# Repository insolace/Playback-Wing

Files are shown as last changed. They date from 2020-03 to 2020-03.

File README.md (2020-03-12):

# Playback-Wing
Concept by Survivor Sound (http://www.survivorsound.com/)

Proof of concept prototype developed by Eric Bateman in 2018

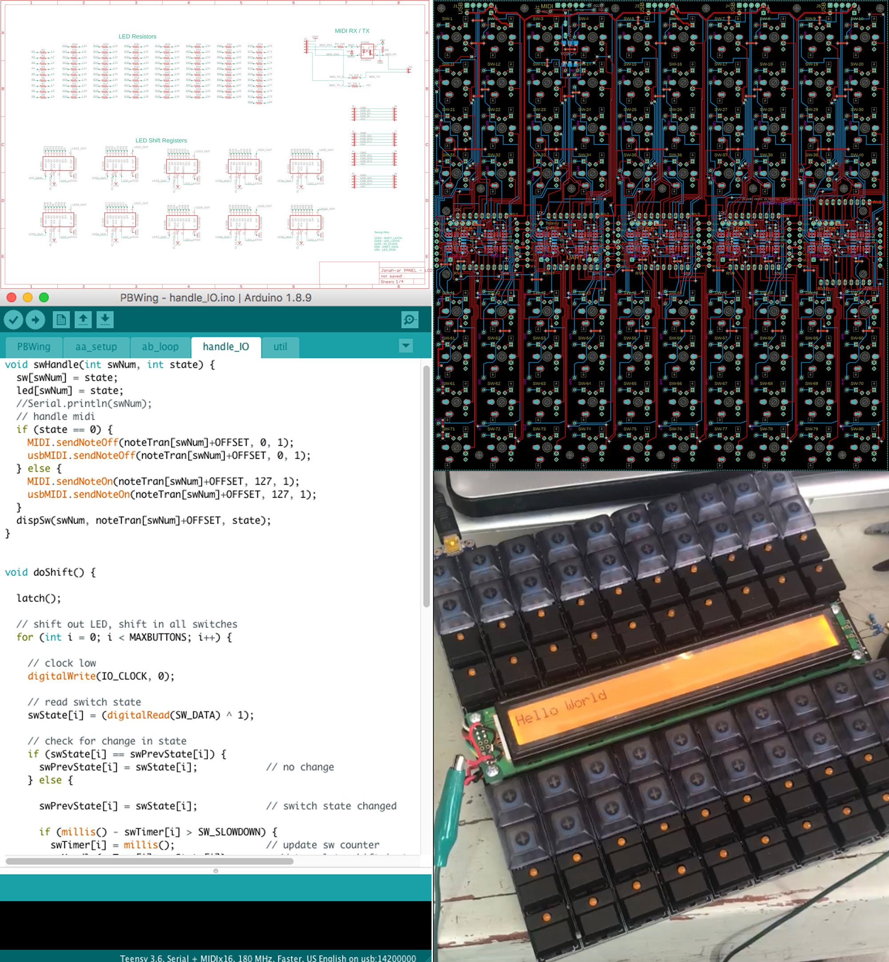
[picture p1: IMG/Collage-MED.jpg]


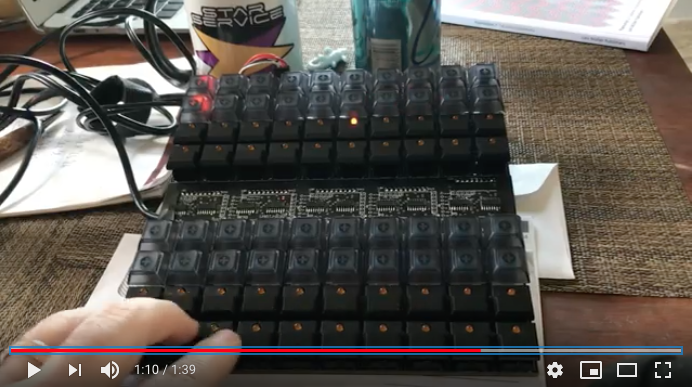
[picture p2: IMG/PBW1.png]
MIDI Demo Video (https://www.youtube.com/watch?v=q78MsimvOyE)
<br>
MIDI DEMO VIDEO (with cat at the end)

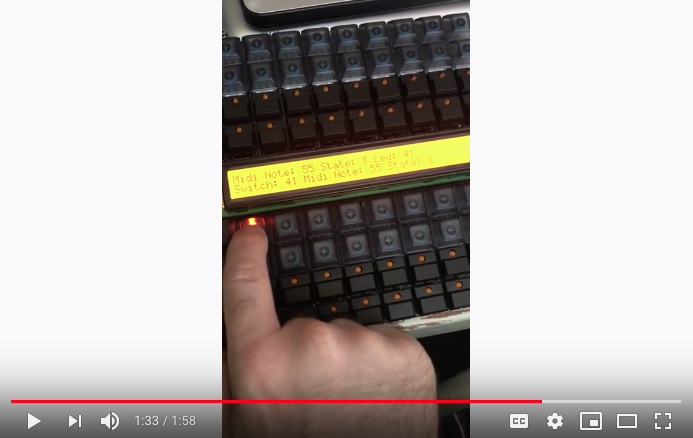
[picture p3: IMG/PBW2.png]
LCD Demo Video (https://www.youtube.com/watch?v=Xt8juDtmMBs)
<br>
LCD DEMO VIDEO

Playback Wing is a portable MIDI powered lighting controller with LCD, meant for use with GrandMA lighting consoles.  

Features:
* Super thick (3/16") PCB, takes any abuse you can throw at it
* PCB uses a custom switch footprint that can accomodate either CherryMX or 5500 series switches, with or without LEDs. Create your own layout! 
* USB and hardware DIN MIDI
* Optional LCD

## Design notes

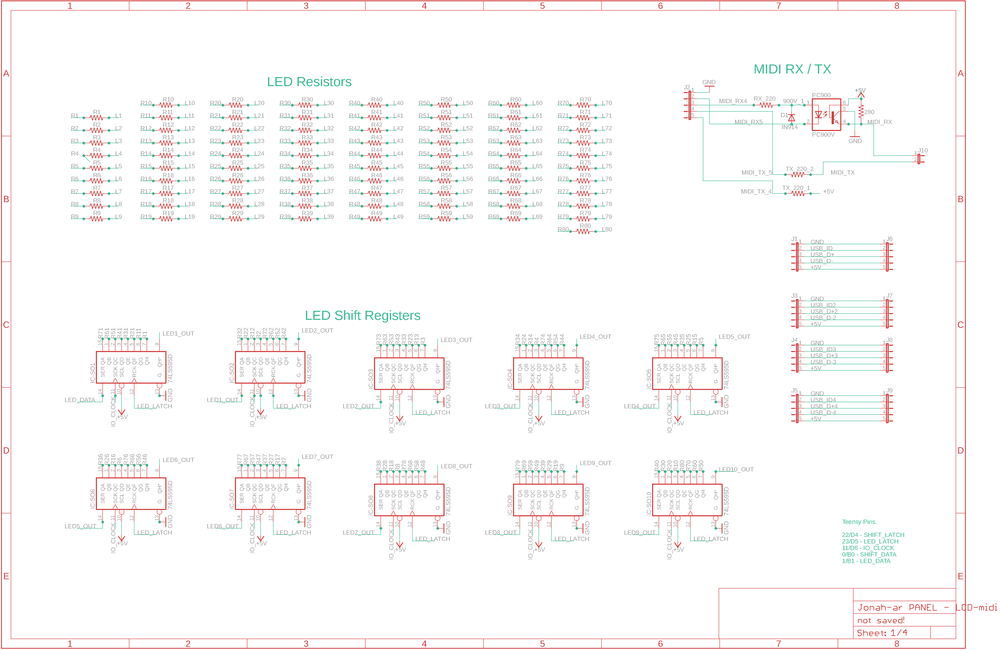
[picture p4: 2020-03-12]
IMG/Schematic pg1.png

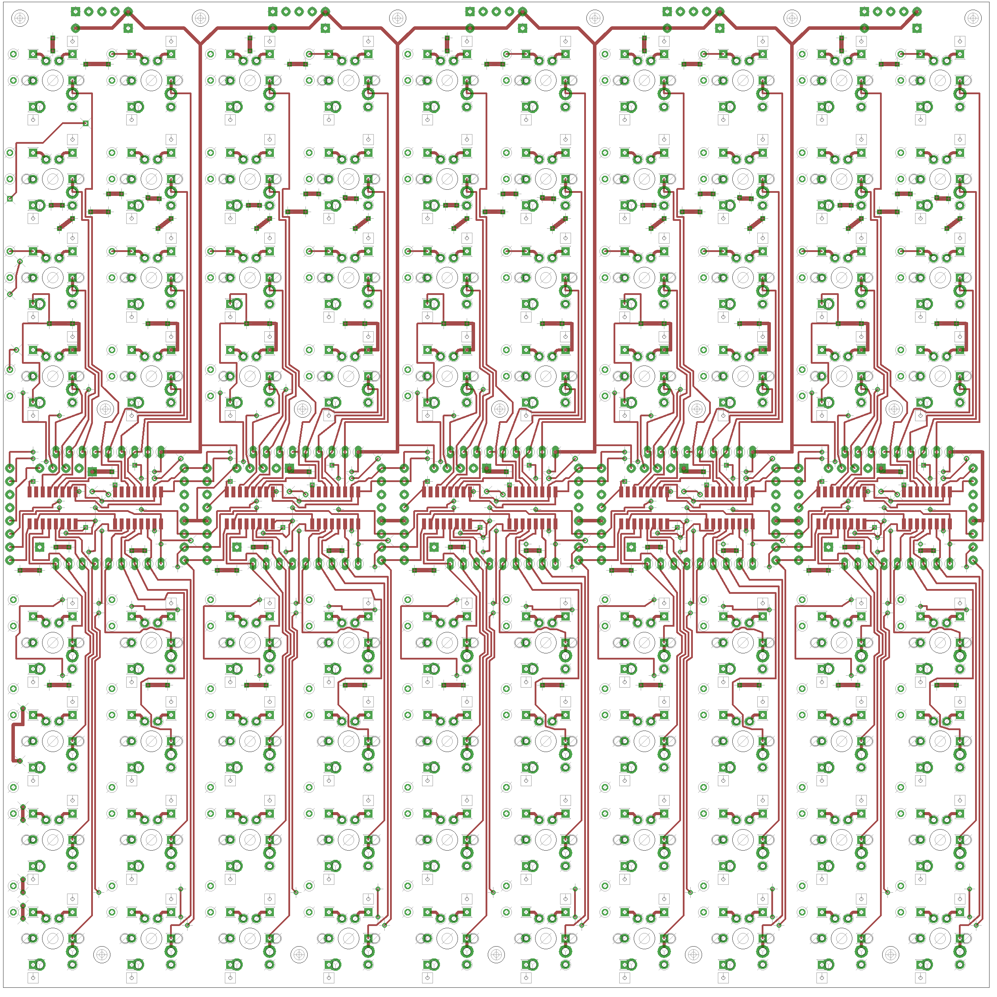
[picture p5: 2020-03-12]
IMG/top-lcd.png

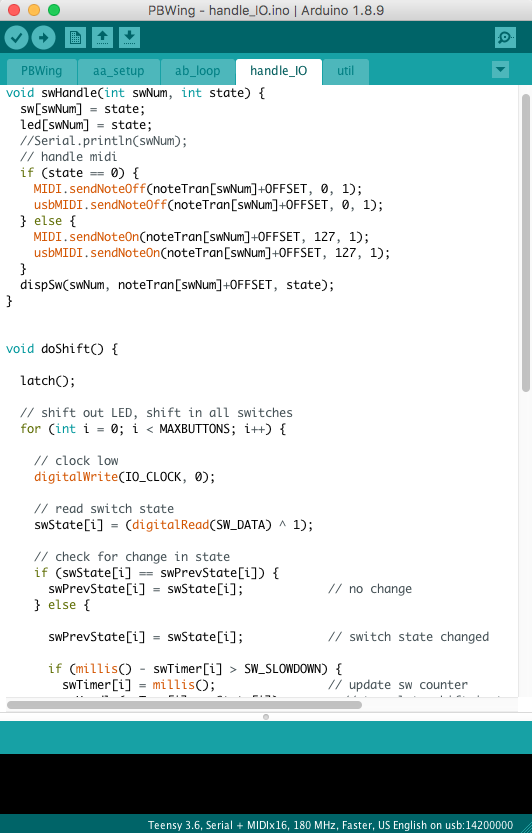
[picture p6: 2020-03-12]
IMG/PBWing-Arduino.png

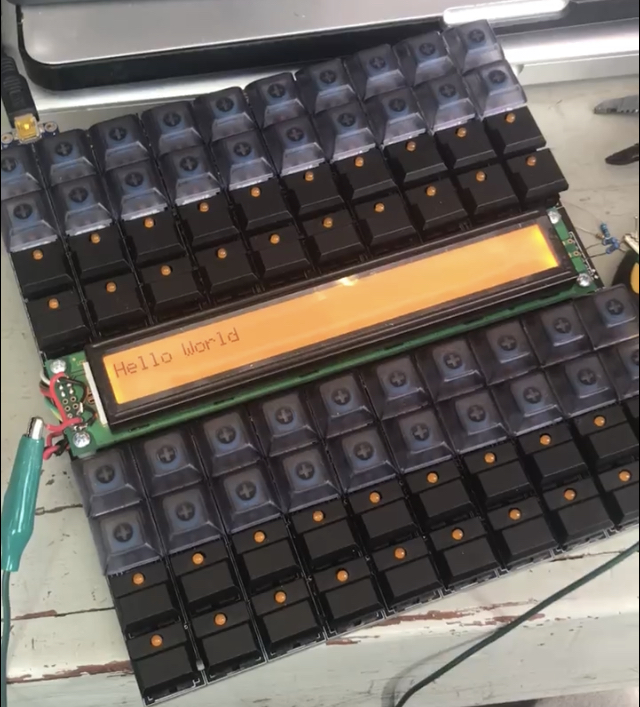
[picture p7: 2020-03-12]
IMG/PBWing.jpg

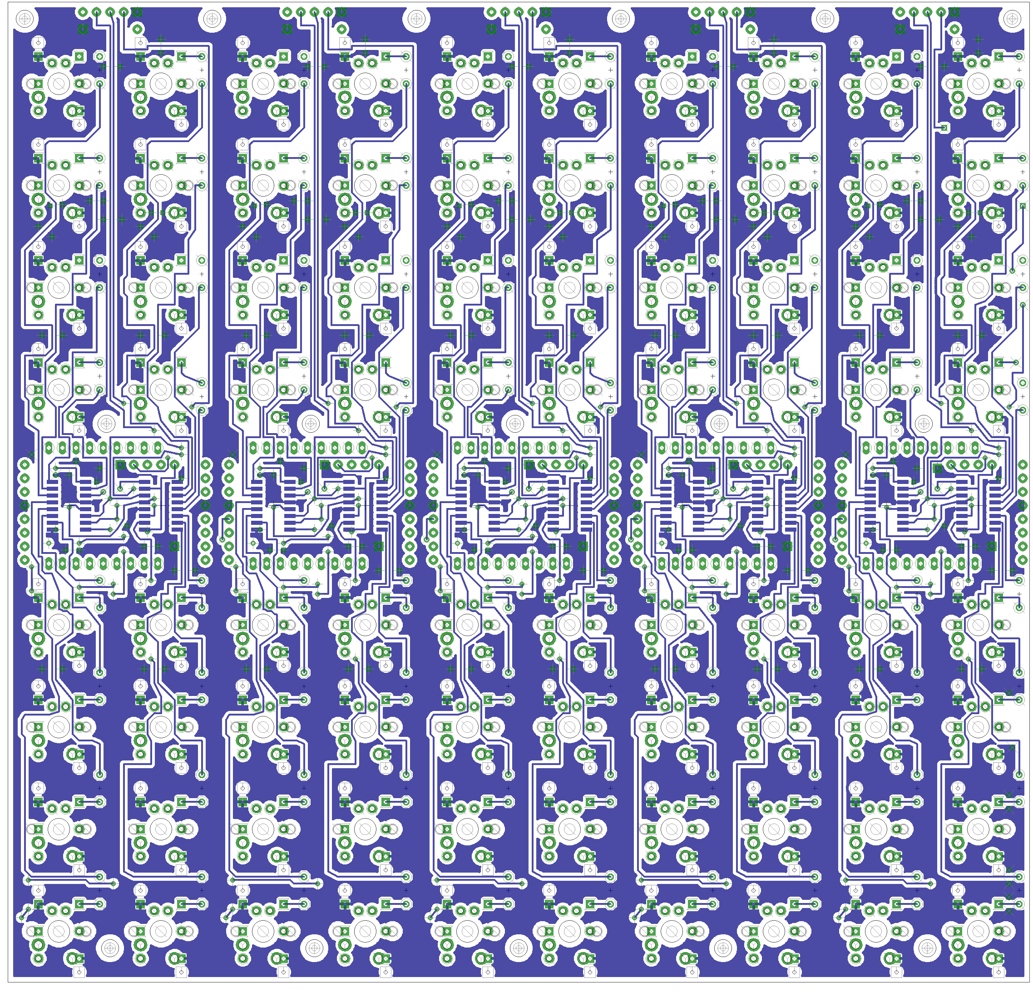
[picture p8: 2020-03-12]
IMG/bot.png

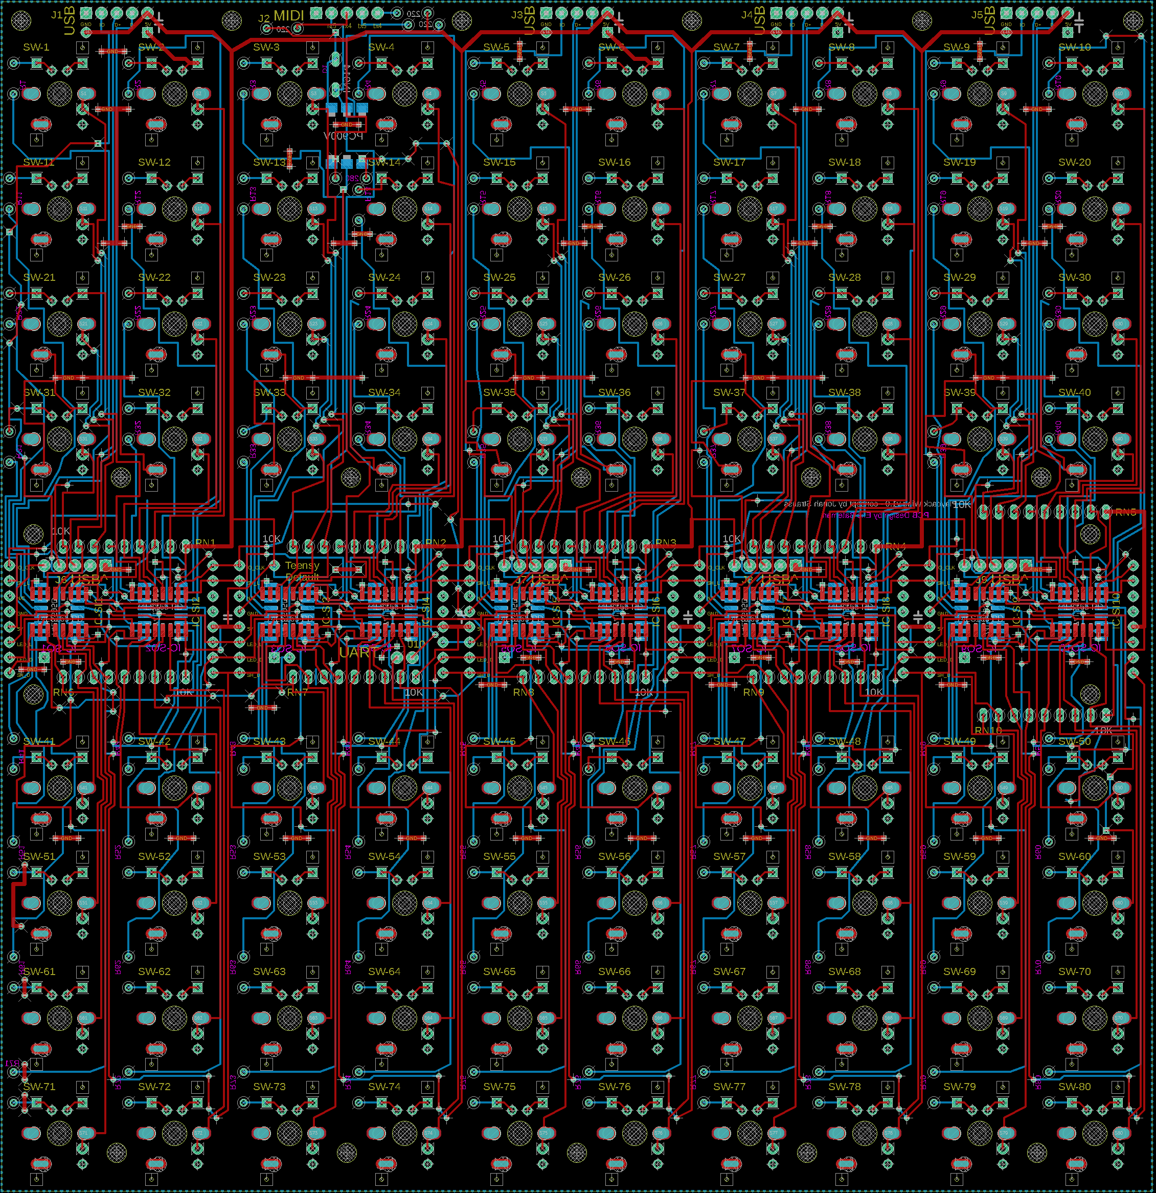
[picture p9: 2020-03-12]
IMG/PCB full.png

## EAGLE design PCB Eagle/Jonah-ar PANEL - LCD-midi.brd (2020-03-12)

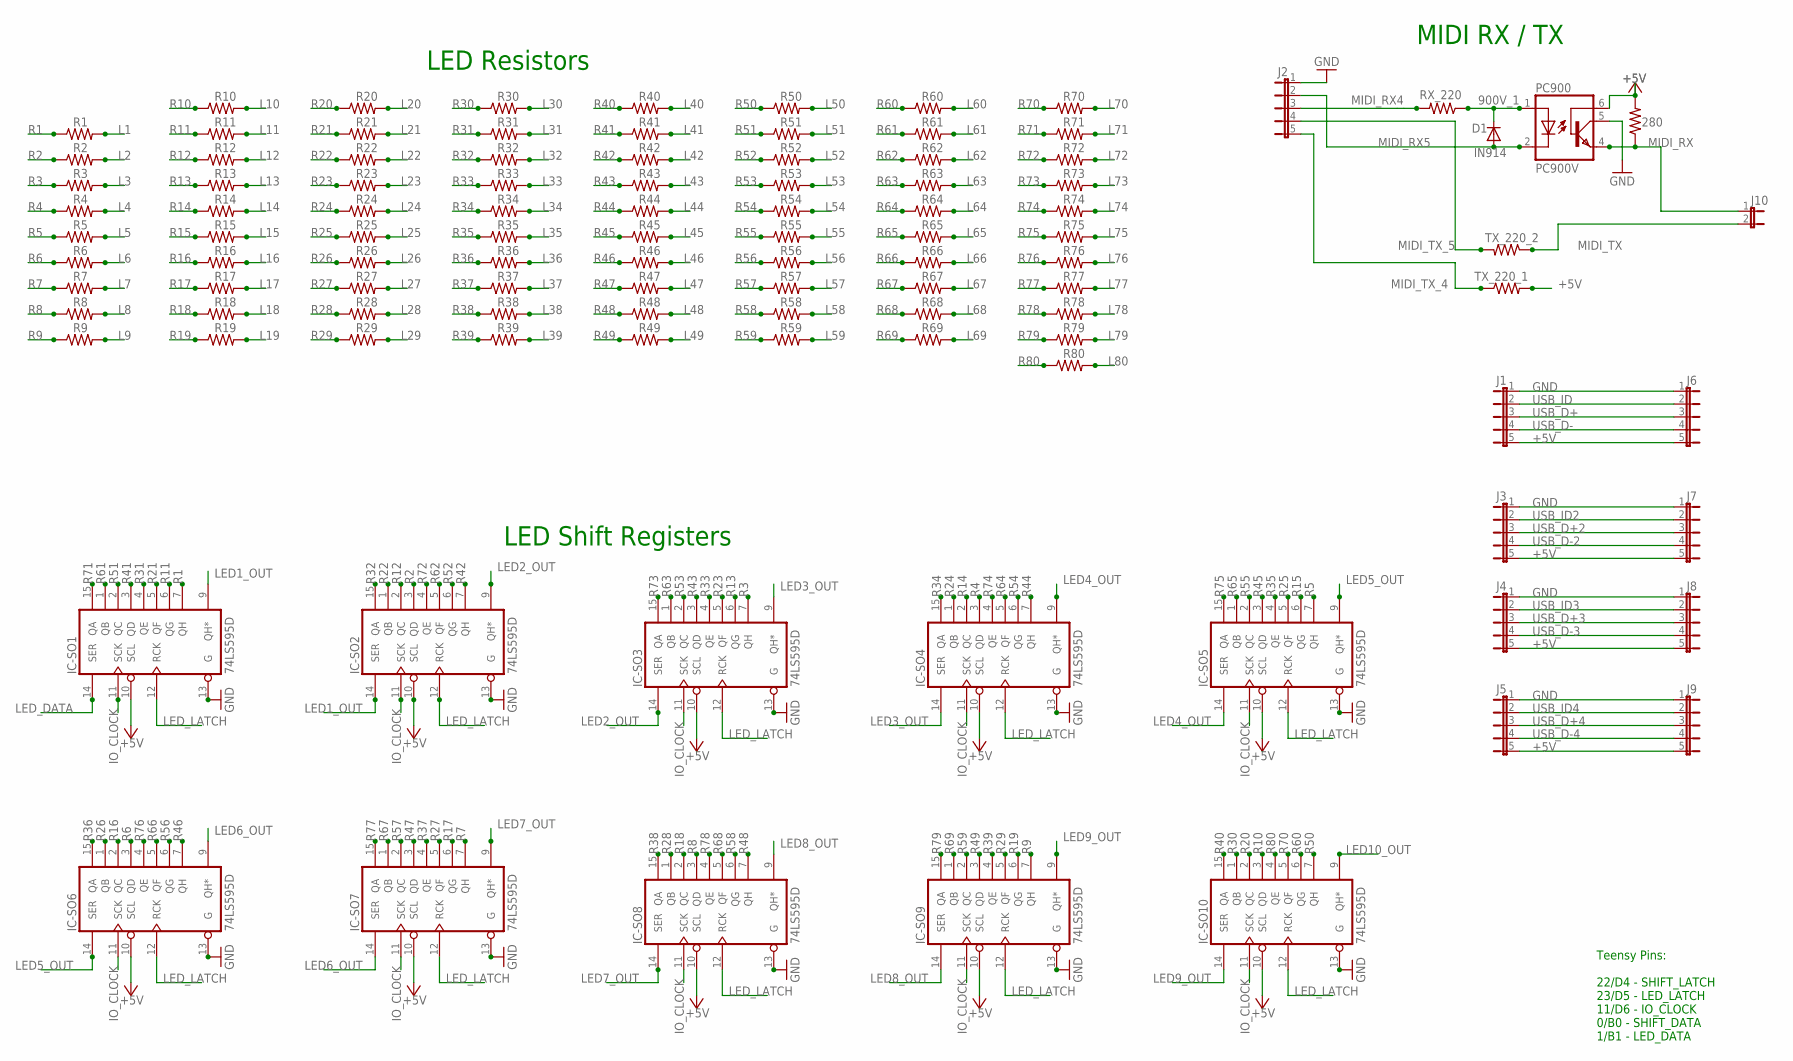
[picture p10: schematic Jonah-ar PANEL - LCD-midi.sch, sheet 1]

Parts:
280: 280; 0204/5
D1: IN914; DO34-7
IC-SO1, IC-SO2, IC-SO3, IC-SO4, IC-SO5, IC-SO6, IC-SO7, IC-SO8, IC-SO9, IC-SO10: 74LS595D; SO16
J1, J2, J3, J4, J5, J6, J7, J8, J9: JP5E; JP5
J10: JP1E; JP1
PC900: PC900V; DIL6-SMD
R1, R2, R3, R4, R5, R6, R7, R8, R9, R10, R11, R12, R13, R14, R15, R16, R17, R18, R19, R20, R21, R22, R23, R24, R25, R26, R27, R28, R29, R30, R31, R32, R33, R34, R35, R36, R37, R38, R39, R40, R41, R42, R43, R44, R45, R46, R47, R48, R49, R50, R51, R52, R53, R54, R55, R56, R57, R58, R59, R60, R61, R62, R63, R64, R65, R66, R67, R68, R69, R70, R71, R72, R73, R74, R75, R76, R77, R78, R79, R80: R-US_0204/5; 0204/5
RX_220: 220; 0204/5
TX_220_1, TX_220_2: 220; 0204/5

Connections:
900V_1: D1.C, PC900.1 (A), RX_220.1
+5V: 280.2, IC-SO1.10 (SCL), IC-SO1.16 (+5V), IC-SO2.10 (SCL), IC-SO2.16 (+5V), IC-SO3.10 (SCL), IC-SO3.16 (+5V), IC-SO4.10 (SCL), IC-SO4.16 (+5V), IC-SO5.10 (SCL), IC-SO5.16 (+5V), IC-SO6.10 (SCL), IC-SO6.16 (+5V), IC-SO7.10 (SCL), IC-SO7.16 (+5V), IC-SO8.10 (SCL), IC-SO8.16 (+5V), IC-SO9.10 (SCL), IC-SO9.16 (+5V), IC-SO10.10 (SCL), IC-SO10.16 (+5V), J1.5, J3.5, J4.5, J5.5, J6.5, J7.5, J8.5, J9.5, PC900.6 (BAS), TX_220_1.2; also elsewhere on the board
GND: IC-SO1.8 (GND), IC-SO1.13 (G), IC-SO2.8 (GND), IC-SO2.13 (G), IC-SO3.8 (GND), IC-SO3.13 (G), IC-SO4.8 (GND), IC-SO4.13 (G), IC-SO5.8 (GND), IC-SO5.13 (G), IC-SO6.8 (GND), IC-SO6.13 (G), IC-SO7.8 (GND), IC-SO7.13 (G), IC-SO8.8 (GND), IC-SO8.13 (G), IC-SO9.8 (GND), IC-SO9.13 (G), IC-SO10.8 (GND), IC-SO10.13 (G), J1.1, J2.1, J3.1, J4.1, J5.1, J6.1, J7.1, J8.1, J9.1, PC900.5 (COL); also elsewhere on the board
IO_CLOCK: IC-SO1.11 (SCK), IC-SO2.11 (SCK), IC-SO3.11 (SCK), IC-SO4.11 (SCK), IC-SO5.11 (SCK), IC-SO6.11 (SCK), IC-SO7.11 (SCK), IC-SO8.11 (SCK), IC-SO9.11 (SCK), IC-SO10.11 (SCK); also elsewhere on the board
L1: R1.2; also elsewhere on the board
L2: R2.2; also elsewhere on the board
L3: R3.2; also elsewhere on the board
L4: R4.2; also elsewhere on the board
L5: R5.2; also elsewhere on the board
L6: R6.2; also elsewhere on the board
L7: R7.2; also elsewhere on the board
L8: R8.2; also elsewhere on the board
L9: R9.2; also elsewhere on the board
L10: R10.2; also elsewhere on the board
L11: R11.2; also elsewhere on the board
L12: R12.2; also elsewhere on the board
L13: R13.2; also elsewhere on the board
L14: R14.2; also elsewhere on the board
L15: R15.2; also elsewhere on the board
L16: R16.2; also elsewhere on the board
L17: R17.2; also elsewhere on the board
L18: R18.2; also elsewhere on the board
L19: R19.2; also elsewhere on the board
L20: R20.2; also elsewhere on the board
L21: R21.2; also elsewhere on the board
L22: R22.2; also elsewhere on the board
L23: R23.2; also elsewhere on the board
L24: R24.2; also elsewhere on the board
L25: R25.2; also elsewhere on the board
L26: R26.2; also elsewhere on the board
L27: R27.2; also elsewhere on the board
L28: R28.2; also elsewhere on the board
L29: R29.2; also elsewhere on the board
L30: R30.2; also elsewhere on the board
L31: R31.2; also elsewhere on the board
L32: R32.2; also elsewhere on the board
L33: R33.2; also elsewhere on the board
L34: R34.2; also elsewhere on the board
L35: R35.2; also elsewhere on the board
L36: R36.2; also elsewhere on the board
L37: R37.2; also elsewhere on the board
L38: R38.2; also elsewhere on the board
L39: R39.2; also elsewhere on the board
L40: R40.2; also elsewhere on the board
L41: R41.2; also elsewhere on the board
L42: R42.2; also elsewhere on the board
L43: R43.2; also elsewhere on the board
L44: R44.2; also elsewhere on the board
L45: R45.2; also elsewhere on the board
L46: R46.2; also elsewhere on the board
L47: R47.2; also elsewhere on the board
L48: R48.2; also elsewhere on the board
L49: R49.2; also elsewhere on the board
L50: R50.2; also elsewhere on the board
L51: R51.2; also elsewhere on the board
L52: R52.2; also elsewhere on the board
L53: R53.2; also elsewhere on the board
L54: R54.2; also elsewhere on the board
L55: R55.2; also elsewhere on the board
L56: R56.2; also elsewhere on the board
L57: R57.2; also elsewhere on the board
L58: R58.2; also elsewhere on the board
L59: R59.2; also elsewhere on the board
L60: R60.2; also elsewhere on the board
L61: R61.2; also elsewhere on the board
L62: R62.2; also elsewhere on the board
L63: R63.2; also elsewhere on the board
L64: R64.2; also elsewhere on the board
L65: R65.2; also elsewhere on the board
L66: R66.2; also elsewhere on the board
L67: R67.2; also elsewhere on the board
L68: R68.2; also elsewhere on the board
L69: R69.2; also elsewhere on the board
L70: R70.2; also elsewhere on the board
L71: R71.2; also elsewhere on the board
L72: R72.2; also elsewhere on the board
L73: R73.2; also elsewhere on the board
L74: R74.2; also elsewhere on the board
L75: R75.2; also elsewhere on the board
L76: R76.2; also elsewhere on the board
L77: R77.2; also elsewhere on the board
L78: R78.2; also elsewhere on the board
L79: R79.2; also elsewhere on the board
L80: R80.2; also elsewhere on the board
LED1_OUT: IC-SO1.9 (QH*), IC-SO2.14 (SER)
LED2_OUT: IC-SO2.9 (QH*), IC-SO3.14 (SER)
LED3_OUT: IC-SO3.9 (QH*), IC-SO4.14 (SER)
LED4_OUT: IC-SO4.9 (QH*), IC-SO5.14 (SER)
LED5_OUT: IC-SO5.9 (QH*), IC-SO6.14 (SER)
LED6_OUT: IC-SO6.9 (QH*), IC-SO7.14 (SER)
LED7_OUT: IC-SO7.9 (QH*), IC-SO8.14 (SER)
LED8_OUT: IC-SO8.9 (QH*), IC-SO9.14 (SER)
LED9_OUT: IC-SO9.9 (QH*), IC-SO10.14 (SER)
LED10_OUT: IC-SO10.9 (QH*)
LED_DATA: IC-SO1.14 (SER)
LED_LATCH: IC-SO1.12 (RCK), IC-SO2.12 (RCK), IC-SO3.12 (RCK), IC-SO4.12 (RCK), IC-SO5.12 (RCK), IC-SO6.12 (RCK), IC-SO7.12 (RCK), IC-SO8.12 (RCK), IC-SO9.12 (RCK), IC-SO10.12 (RCK)
MIDI_RX: 280.1, J10.1, PC900.4 (EMI)
MIDI_RX4: J2.3, RX_220.2
MIDI_RX5: D1.A, J2.2, PC900.2 (C)
MIDI_TX: J10.2, TX_220_2.1
MIDI_TX_4: J2.5, TX_220_1.1
MIDI_TX_5: J2.4, TX_220_2.2
R1: IC-SO1.7 (QH), R1.1
R2: IC-SO2.3 (QD), R2.1
R3: IC-SO3.7 (QH), R3.1
R4: IC-SO4.3 (QD), R4.1
R5: IC-SO5.7 (QH), R5.1
R6: IC-SO6.3 (QD), R6.1
R7: IC-SO7.7 (QH), R7.1
R8: IC-SO8.3 (QD), R8.1
R9: IC-SO9.7 (QH), R9.1
R10: IC-SO10.3 (QD), R10.1
R11: IC-SO1.6 (QG), R11.1
R12: IC-SO2.2 (QC), R12.1
R13: IC-SO3.6 (QG), R13.1
R14: IC-SO4.2 (QC), R14.1
R15: IC-SO5.6 (QG), R15.1
R16: IC-SO6.2 (QC), R16.1
R17: IC-SO7.6 (QG), R17.1
R18: IC-SO8.2 (QC), R18.1
R19: IC-SO9.6 (QG), R19.1
R20: IC-SO10.2 (QC), R20.1
R21: IC-SO1.5 (QF), R21.1
R22: IC-SO2.1 (QB), R22.1
R23: IC-SO3.5 (QF), R23.1
R24: IC-SO4.1 (QB), R24.1
R25: IC-SO5.5 (QF), R25.1
R26: IC-SO6.1 (QB), R26.1
R27: IC-SO7.5 (QF), R27.1
R28: IC-SO8.1 (QB), R28.1
R29: IC-SO9.5 (QF), R29.1
R30: IC-SO10.1 (QB), R30.1
R31: IC-SO1.4 (QE), R31.1
R32: IC-SO2.15 (QA), R32.1
R33: IC-SO3.4 (QE), R33.1
R34: IC-SO4.15 (QA), R34.1
R35: IC-SO5.4 (QE), R35.1
R36: IC-SO6.15 (QA), R36.1
R37: IC-SO7.4 (QE), R37.1
R38: IC-SO8.15 (QA), R38.1
R39: IC-SO9.4 (QE), R39.1
R40: IC-SO10.15 (QA), R40.1
R41: IC-SO1.3 (QD), R41.1
R42: IC-SO2.7 (QH), R42.1
R43: IC-SO3.3 (QD), R43.1
R44: IC-SO4.7 (QH), R44.1
R45: IC-SO5.3 (QD), R45.1
R46: IC-SO6.7 (QH), R46.1
R47: IC-SO7.3 (QD), R47.1
R48: IC-SO8.7 (QH), R48.1
R49: IC-SO9.3 (QD), R49.1
R50: IC-SO10.7 (QH), R50.1
R51: IC-SO1.2 (QC), R51.1
R52: IC-SO2.6 (QG), R52.1
R53: IC-SO3.2 (QC), R53.1
R54: IC-SO4.6 (QG), R54.1
R55: IC-SO5.2 (QC), R55.1
R56: IC-SO6.6 (QG), R56.1
R57: IC-SO7.2 (QC), R57.1
R58: IC-SO8.6 (QG), R58.1
R59: IC-SO9.2 (QC), R59.1
R60: IC-SO10.6 (QG), R60.1
R61: IC-SO1.1 (QB), R61.1
R62: IC-SO2.5 (QF), R62.1
R63: IC-SO3.1 (QB), R63.1
R64: IC-SO4.5 (QF), R64.1
R65: IC-SO5.1 (QB), R65.1
R66: IC-SO6.5 (QF), R66.1
R67: IC-SO7.1 (QB), R67.1
R68: IC-SO8.5 (QF), R68.1
R69: IC-SO9.1 (QB), R69.1
R70: IC-SO10.5 (QF), R70.1
R71: IC-SO1.15 (QA), R71.1
R72: IC-SO2.4 (QE), R72.1
R73: IC-SO3.15 (QA), R73.1
R74: IC-SO4.4 (QE), R74.1
R75: IC-SO5.15 (QA), R75.1
R76: IC-SO6.4 (QE), R76.1
R77: IC-SO7.15 (QA), R77.1
R78: IC-SO8.4 (QE), R78.1
R79: IC-SO9.15 (QA), R79.1
R80: IC-SO10.4 (QE), R80.1
USB_D+: J1.3, J6.3
USB_D+2: J3.3, J7.3
USB_D+3: J4.3, J8.3
USB_D+4: J5.3, J9.3
USB_D-: J1.4, J6.4
USB_D-2: J3.4, J7.4
USB_D-3: J4.4, J8.4
USB_D-4: J5.4, J9.4
USB_ID: J1.2, J6.2
USB_ID2: J3.2, J7.2
USB_ID3: J4.2, J8.2
USB_ID4: J5.2, J9.2

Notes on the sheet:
Teensy Pins: 22/D4 - SHIFT_LATCH 23/D5 - LED_LATCH 11/D6 - IO_CLOCK 0/B0 - SHIFT_DATA 1/B1 - LED_DATA
MIDI RX / TX
LED Resistors
LED Shift Registers

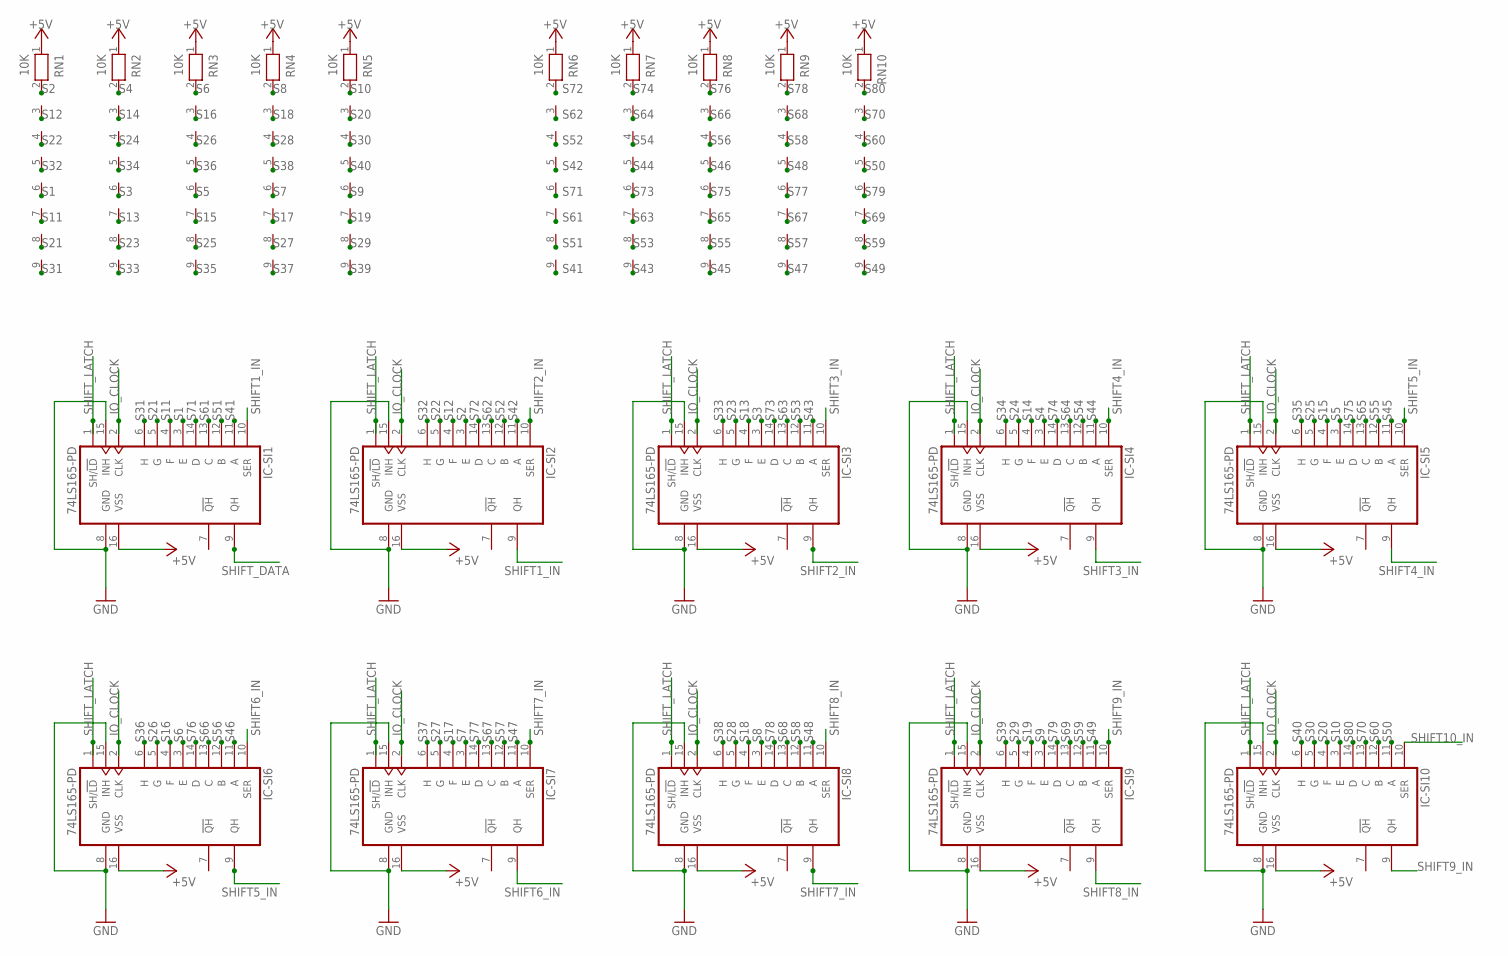
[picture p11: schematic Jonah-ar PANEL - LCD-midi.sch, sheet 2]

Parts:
IC-SI1, IC-SI2, IC-SI3, IC-SI4, IC-SI5, IC-SI6, IC-SI7, IC-SI8, IC-SI9, IC-SI10: 74LS165-PD; SO16
RN1, RN2, RN3, RN4, RN5, RN6, RN7, RN8, RN9, RN10: 10K; RN-9

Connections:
+5V: IC-SI1.16 (VSS), IC-SI2.16 (VSS), IC-SI3.16 (VSS), IC-SI4.16 (VSS), IC-SI5.16 (VSS), IC-SI6.16 (VSS), IC-SI7.16 (VSS), IC-SI8.16 (VSS), IC-SI9.16 (VSS), IC-SI10.16 (VSS), RN1.1, RN2.1, RN3.1, RN4.1, RN5.1, RN6.1, RN7.1, RN8.1, RN9.1, RN10.1; also elsewhere on the board
GND: IC-SI1.8 (GND), IC-SI1.15 (INH), IC-SI2.8 (GND), IC-SI2.15 (INH), IC-SI3.8 (GND), IC-SI3.15 (INH), IC-SI4.8 (GND), IC-SI4.15 (INH), IC-SI5.8 (GND), IC-SI5.15 (INH), IC-SI6.8 (GND), IC-SI6.15 (INH), IC-SI7.8 (GND), IC-SI7.15 (INH), IC-SI8.8 (GND), IC-SI8.15 (INH), IC-SI9.8 (GND), IC-SI9.15 (INH), IC-SI10.8 (GND), IC-SI10.15 (INH); also elsewhere on the board
IO_CLOCK: IC-SI1.2 (CLK), IC-SI2.2 (CLK), IC-SI3.2 (CLK), IC-SI4.2 (CLK), IC-SI5.2 (CLK), IC-SI6.2 (CLK), IC-SI7.2 (CLK), IC-SI8.2 (CLK), IC-SI9.2 (CLK), IC-SI10.2 (CLK); also elsewhere on the board
S1: IC-SI1.3 (E), RN1.6; also elsewhere on the board
S2: IC-SI2.3 (E), RN1.2; also elsewhere on the board
S3: IC-SI3.3 (E), RN2.6; also elsewhere on the board
S4: IC-SI4.3 (E), RN2.2; also elsewhere on the board
S5: IC-SI5.3 (E), RN3.6; also elsewhere on the board
S6: IC-SI6.3 (E), RN3.2; also elsewhere on the board
S7: IC-SI7.3 (E), RN4.6; also elsewhere on the board
S8: IC-SI8.3 (E), RN4.2; also elsewhere on the board
S9: IC-SI9.3 (E), RN5.6; also elsewhere on the board
S10: IC-SI10.3 (E), RN5.2; also elsewhere on the board
S11: IC-SI1.4 (F), RN1.7; also elsewhere on the board
S12: IC-SI2.4 (F), RN1.3; also elsewhere on the board
S13: IC-SI3.4 (F), RN2.7; also elsewhere on the board
S14: IC-SI4.4 (F), RN2.3; also elsewhere on the board
S15: IC-SI5.4 (F), RN3.7; also elsewhere on the board
S16: IC-SI6.4 (F), RN3.3; also elsewhere on the board
S17: IC-SI7.4 (F), RN4.7; also elsewhere on the board
S18: IC-SI8.4 (F), RN4.3; also elsewhere on the board
S19: IC-SI9.4 (F), RN5.7; also elsewhere on the board
S20: IC-SI10.4 (F), RN5.3; also elsewhere on the board
S21: IC-SI1.5 (G), RN1.8; also elsewhere on the board
S22: IC-SI2.5 (G), RN1.4; also elsewhere on the board
S23: IC-SI3.5 (G), RN2.8; also elsewhere on the board
S24: IC-SI4.5 (G), RN2.4; also elsewhere on the board
S25: IC-SI5.5 (G), RN3.8; also elsewhere on the board
S26: IC-SI6.5 (G), RN3.4; also elsewhere on the board
S27: IC-SI7.5 (G), RN4.8; also elsewhere on the board
S28: IC-SI8.5 (G), RN4.4; also elsewhere on the board
S29: IC-SI9.5 (G), RN5.8; also elsewhere on the board
S30: IC-SI10.5 (G), RN5.4; also elsewhere on the board
S31: IC-SI1.6 (H), RN1.9; also elsewhere on the board
S32: IC-SI2.6 (H), RN1.5; also elsewhere on the board
S33: IC-SI3.6 (H), RN2.9; also elsewhere on the board
S34: IC-SI4.6 (H), RN2.5; also elsewhere on the board
S35: IC-SI5.6 (H), RN3.9; also elsewhere on the board
S36: IC-SI6.6 (H), RN3.5; also elsewhere on the board
S37: IC-SI7.6 (H), RN4.9; also elsewhere on the board
S38: IC-SI8.6 (H), RN4.5; also elsewhere on the board
S39: IC-SI9.6 (H), RN5.9; also elsewhere on the board
S40: IC-SI10.6 (H), RN5.5; also elsewhere on the board
S41: IC-SI1.11 (A), RN6.9; also elsewhere on the board
S42: IC-SI2.11 (A), RN6.5; also elsewhere on the board
S43: IC-SI3.11 (A), RN7.9; also elsewhere on the board
S44: IC-SI4.11 (A), RN7.5; also elsewhere on the board
S45: IC-SI5.11 (A), RN8.9; also elsewhere on the board
S46: IC-SI6.11 (A), RN8.5; also elsewhere on the board
S47: IC-SI7.11 (A), RN9.9; also elsewhere on the board
S48: IC-SI8.11 (A), RN9.5; also elsewhere on the board
S49: IC-SI9.11 (A), RN10.9; also elsewhere on the board
S50: IC-SI10.11 (A), RN10.5; also elsewhere on the board
S51: IC-SI1.12 (B), RN6.8; also elsewhere on the board
S52: IC-SI2.12 (B), RN6.4; also elsewhere on the board
S53: IC-SI3.12 (B), RN7.8; also elsewhere on the board
S54: IC-SI4.12 (B), RN7.4; also elsewhere on the board
S55: IC-SI5.12 (B), RN8.8; also elsewhere on the board
S56: IC-SI6.12 (B), RN8.4; also elsewhere on the board
S57: IC-SI7.12 (B), RN9.8; also elsewhere on the board
S58: IC-SI8.12 (B), RN9.4; also elsewhere on the board
S59: IC-SI9.12 (B), RN10.8; also elsewhere on the board
S60: IC-SI10.12 (B), RN10.4; also elsewhere on the board
S61: IC-SI1.13 (C), RN6.7; also elsewhere on the board
S62: IC-SI2.13 (C), RN6.3; also elsewhere on the board
S63: IC-SI3.13 (C), RN7.7; also elsewhere on the board
S64: IC-SI4.13 (C), RN7.3; also elsewhere on the board
S65: IC-SI5.13 (C), RN8.7; also elsewhere on the board
S66: IC-SI6.13 (C), RN8.3; also elsewhere on the board
S67: IC-SI7.13 (C), RN9.7; also elsewhere on the board
S68: IC-SI8.13 (C), RN9.3; also elsewhere on the board
S69: IC-SI9.13 (C), RN10.7; also elsewhere on the board
S70: IC-SI10.13 (C), RN10.3; also elsewhere on the board
S71: IC-SI1.14 (D), RN6.6; also elsewhere on the board
S72: IC-SI2.14 (D), RN6.2; also elsewhere on the board
S73: IC-SI3.14 (D), RN7.6; also elsewhere on the board
S74: IC-SI4.14 (D), RN7.2; also elsewhere on the board
S75: IC-SI5.14 (D), RN8.6; also elsewhere on the board
S76: IC-SI6.14 (D), RN8.2; also elsewhere on the board
S77: IC-SI7.14 (D), RN9.6; also elsewhere on the board
S78: IC-SI8.14 (D), RN9.2; also elsewhere on the board
S79: IC-SI9.14 (D), RN10.6; also elsewhere on the board
S80: IC-SI10.14 (D), RN10.2; also elsewhere on the board
SHIFT1_IN: IC-SI1.10 (SER), IC-SI2.9 (QH)
SHIFT2_IN: IC-SI2.10 (SER), IC-SI3.9 (QH)
SHIFT3_IN: IC-SI3.10 (SER), IC-SI4.9 (QH)
SHIFT4_IN: IC-SI4.10 (SER), IC-SI5.9 (QH)
SHIFT5_IN: IC-SI5.10 (SER), IC-SI6.9 (QH)
SHIFT6_IN: IC-SI6.10 (SER), IC-SI7.9 (QH)
SHIFT7_IN: IC-SI7.10 (SER), IC-SI8.9 (QH)
SHIFT8_IN: IC-SI8.10 (SER), IC-SI9.9 (QH)
SHIFT9_IN: IC-SI9.10 (SER), IC-SI10.9 (QH)
SHIFT10_IN: IC-SI10.10 (SER)
SHIFT_DATA: IC-SI1.9 (QH)
SHIFT_LATCH: IC-SI1.1 (SH/!LD), IC-SI2.1 (SH/!LD), IC-SI3.1 (SH/!LD), IC-SI4.1 (SH/!LD), IC-SI5.1 (SH/!LD), IC-SI6.1 (SH/!LD), IC-SI7.1 (SH/!LD), IC-SI8.1 (SH/!LD), IC-SI9.1 (SH/!LD), IC-SI10.1 (SH/!LD)

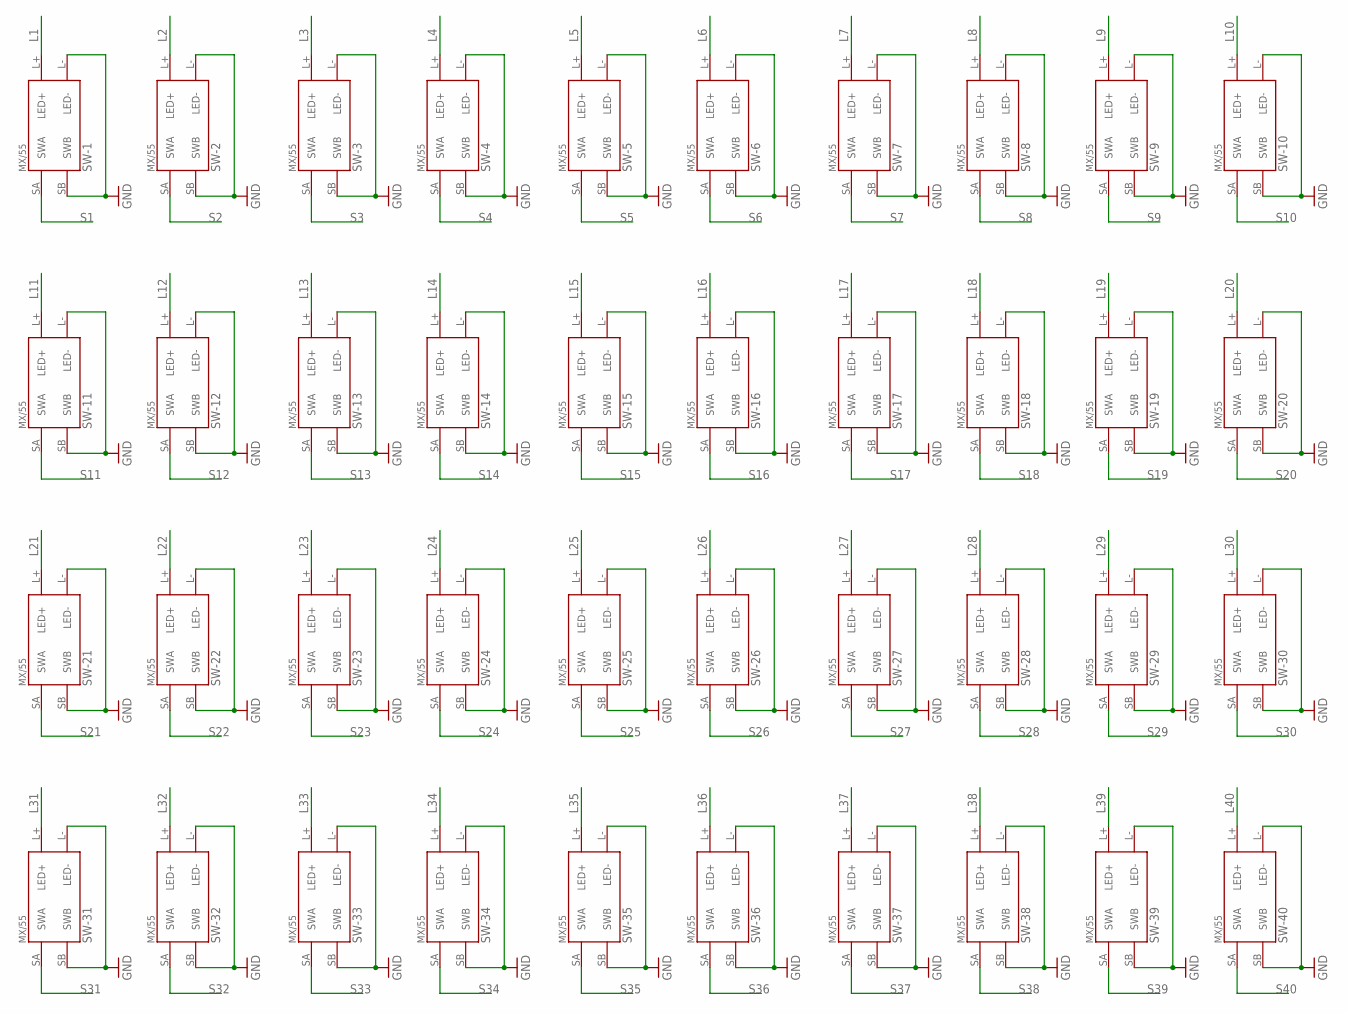
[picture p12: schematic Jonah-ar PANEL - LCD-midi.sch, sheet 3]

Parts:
SW-1, SW-2, SW-3, SW-4, SW-5, SW-6, SW-7, SW-8, SW-9, SW-10, SW-11, SW-12, SW-13, SW-14, SW-15, SW-16, SW-17, SW-18, SW-19, SW-20, SW-21, SW-22, SW-23, SW-24, SW-25, SW-26, SW-27, SW-28, SW-29, SW-30, SW-31, SW-32, SW-33, SW-34, SW-35, SW-36, SW-37, SW-38, SW-39, SW-40: CHERRY-MX-LED

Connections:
GND: SW-1.L- (LED-), SW-1.SB (SWB), SW-2.L- (LED-), SW-2.SB (SWB), SW-3.L- (LED-), SW-3.SB (SWB), SW-4.L- (LED-), SW-4.SB (SWB), SW-5.L- (LED-), SW-5.SB (SWB), SW-6.L- (LED-), SW-6.SB (SWB), SW-7.L- (LED-), SW-7.SB (SWB), SW-8.L- (LED-), SW-8.SB (SWB), SW-9.L- (LED-), SW-9.SB (SWB), SW-10.L- (LED-), SW-10.SB (SWB), SW-11.L- (LED-), SW-11.SB (SWB), SW-12.L- (LED-), SW-12.SB (SWB), SW-13.L- (LED-), SW-13.SB (SWB), SW-14.L- (LED-), SW-14.SB (SWB), SW-15.L- (LED-), SW-15.SB (SWB), SW-16.L- (LED-), SW-16.SB (SWB), SW-17.L- (LED-), SW-17.SB (SWB), SW-18.L- (LED-), SW-18.SB (SWB), SW-19.L- (LED-), SW-19.SB (SWB), SW-20.L- (LED-), SW-20.SB (SWB), SW-21.L- (LED-), SW-21.SB (SWB), SW-22.L- (LED-), SW-22.SB (SWB), SW-23.L- (LED-), SW-23.SB (SWB), SW-24.L- (LED-), SW-24.SB (SWB), SW-25.L- (LED-), SW-25.SB (SWB), SW-26.L- (LED-), SW-26.SB (SWB), SW-27.L- (LED-), SW-27.SB (SWB), SW-28.L- (LED-), SW-28.SB (SWB), SW-29.L- (LED-), SW-29.SB (SWB), SW-30.L- (LED-), SW-30.SB (SWB), SW-31.L- (LED-), SW-31.SB (SWB), SW-32.L- (LED-), SW-32.SB (SWB), SW-33.L- (LED-), SW-33.SB (SWB), SW-34.L- (LED-), SW-34.SB (SWB), SW-35.L- (LED-), SW-35.SB (SWB), SW-36.L- (LED-), SW-36.SB (SWB), SW-37.L- (LED-), SW-37.SB (SWB), SW-38.L- (LED-), SW-38.SB (SWB), SW-39.L- (LED-), SW-39.SB (SWB), SW-40.L- (LED-), SW-40.SB (SWB); also elsewhere on the board
L1: SW-1.L+ (LED+); also elsewhere on the board
L2: SW-2.L+ (LED+); also elsewhere on the board
L3: SW-3.L+ (LED+); also elsewhere on the board
L4: SW-4.L+ (LED+); also elsewhere on the board
L5: SW-5.L+ (LED+); also elsewhere on the board
L6: SW-6.L+ (LED+); also elsewhere on the board
L7: SW-7.L+ (LED+); also elsewhere on the board
L8: SW-8.L+ (LED+); also elsewhere on the board
L9: SW-9.L+ (LED+); also elsewhere on the board
L10: SW-10.L+ (LED+); also elsewhere on the board
L11: SW-11.L+ (LED+); also elsewhere on the board
L12: SW-12.L+ (LED+); also elsewhere on the board
L13: SW-13.L+ (LED+); also elsewhere on the board
L14: SW-14.L+ (LED+); also elsewhere on the board
L15: SW-15.L+ (LED+); also elsewhere on the board
L16: SW-16.L+ (LED+); also elsewhere on the board
L17: SW-17.L+ (LED+); also elsewhere on the board
L18: SW-18.L+ (LED+); also elsewhere on the board
L19: SW-19.L+ (LED+); also elsewhere on the board
L20: SW-20.L+ (LED+); also elsewhere on the board
L21: SW-21.L+ (LED+); also elsewhere on the board
L22: SW-22.L+ (LED+); also elsewhere on the board
L23: SW-23.L+ (LED+); also elsewhere on the board
L24: SW-24.L+ (LED+); also elsewhere on the board
L25: SW-25.L+ (LED+); also elsewhere on the board
L26: SW-26.L+ (LED+); also elsewhere on the board
L27: SW-27.L+ (LED+); also elsewhere on the board
L28: SW-28.L+ (LED+); also elsewhere on the board
L29: SW-29.L+ (LED+); also elsewhere on the board
L30: SW-30.L+ (LED+); also elsewhere on the board
L31: SW-31.L+ (LED+); also elsewhere on the board
L32: SW-32.L+ (LED+); also elsewhere on the board
L33: SW-33.L+ (LED+); also elsewhere on the board
L34: SW-34.L+ (LED+); also elsewhere on the board
L35: SW-35.L+ (LED+); also elsewhere on the board
L36: SW-36.L+ (LED+); also elsewhere on the board
L37: SW-37.L+ (LED+); also elsewhere on the board
L38: SW-38.L+ (LED+); also elsewhere on the board
L39: SW-39.L+ (LED+); also elsewhere on the board
L40: SW-40.L+ (LED+); also elsewhere on the board
S1: SW-1.SA (SWA); also elsewhere on the board
S2: SW-2.SA (SWA); also elsewhere on the board
S3: SW-3.SA (SWA); also elsewhere on the board
S4: SW-4.SA (SWA); also elsewhere on the board
S5: SW-5.SA (SWA); also elsewhere on the board
S6: SW-6.SA (SWA); also elsewhere on the board
S7: SW-7.SA (SWA); also elsewhere on the board
S8: SW-8.SA (SWA); also elsewhere on the board
S9: SW-9.SA (SWA); also elsewhere on the board
S10: SW-10.SA (SWA); also elsewhere on the board
S11: SW-11.SA (SWA); also elsewhere on the board
S12: SW-12.SA (SWA); also elsewhere on the board
S13: SW-13.SA (SWA); also elsewhere on the board
S14: SW-14.SA (SWA); also elsewhere on the board
S15: SW-15.SA (SWA); also elsewhere on the board
S16: SW-16.SA (SWA); also elsewhere on the board
S17: SW-17.SA (SWA); also elsewhere on the board
S18: SW-18.SA (SWA); also elsewhere on the board
S19: SW-19.SA (SWA); also elsewhere on the board
S20: SW-20.SA (SWA); also elsewhere on the board
S21: SW-21.SA (SWA); also elsewhere on the board
S22: SW-22.SA (SWA); also elsewhere on the board
S23: SW-23.SA (SWA); also elsewhere on the board
S24: SW-24.SA (SWA); also elsewhere on the board
S25: SW-25.SA (SWA); also elsewhere on the board
S26: SW-26.SA (SWA); also elsewhere on the board
S27: SW-27.SA (SWA); also elsewhere on the board
S28: SW-28.SA (SWA); also elsewhere on the board
S29: SW-29.SA (SWA); also elsewhere on the board
S30: SW-30.SA (SWA); also elsewhere on the board
S31: SW-31.SA (SWA); also elsewhere on the board
S32: SW-32.SA (SWA); also elsewhere on the board
S33: SW-33.SA (SWA); also elsewhere on the board
S34: SW-34.SA (SWA); also elsewhere on the board
S35: SW-35.SA (SWA); also elsewhere on the board
S36: SW-36.SA (SWA); also elsewhere on the board
S37: SW-37.SA (SWA); also elsewhere on the board
S38: SW-38.SA (SWA); also elsewhere on the board
S39: SW-39.SA (SWA); also elsewhere on the board
S40: SW-40.SA (SWA); also elsewhere on the board

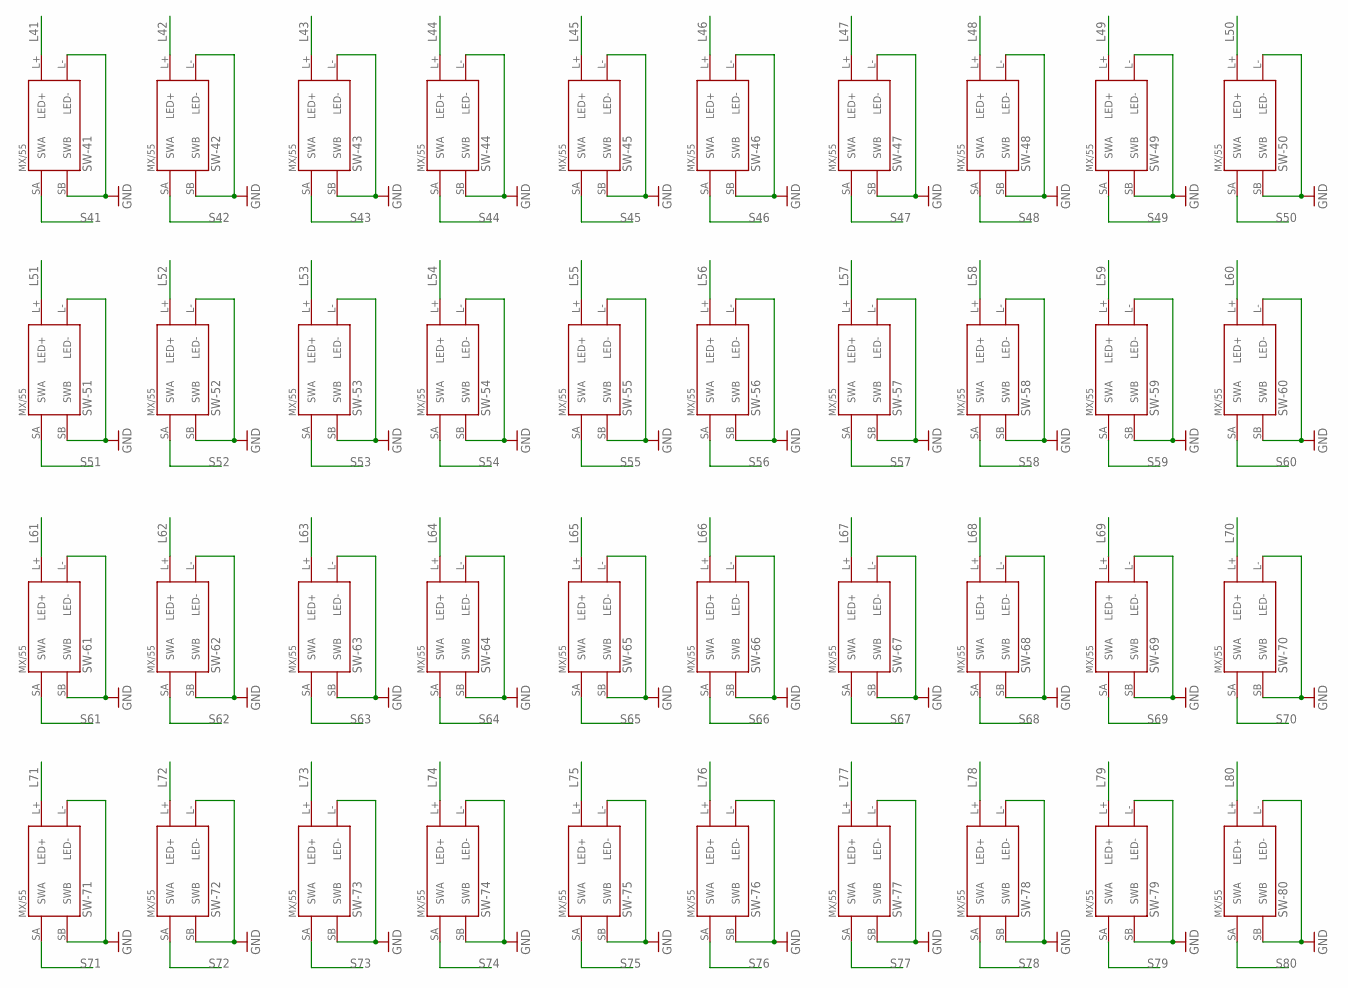
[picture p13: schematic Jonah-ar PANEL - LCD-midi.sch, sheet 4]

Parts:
SW-41, SW-42, SW-43, SW-44, SW-45, SW-46, SW-47, SW-48, SW-49, SW-50, SW-51, SW-52, SW-53, SW-54, SW-55, SW-56, SW-57, SW-58, SW-59, SW-60, SW-61, SW-62, SW-63, SW-64, SW-65, SW-66, SW-67, SW-68, SW-69, SW-70, SW-71, SW-72, SW-73, SW-74, SW-75, SW-76, SW-77, SW-78, SW-79, SW-80: CHERRY-MX-LED

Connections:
GND: SW-41.L- (LED-), SW-41.SB (SWB), SW-42.L- (LED-), SW-42.SB (SWB), SW-43.L- (LED-), SW-43.SB (SWB), SW-44.L- (LED-), SW-44.SB (SWB), SW-45.L- (LED-), SW-45.SB (SWB), SW-46.L- (LED-), SW-46.SB (SWB), SW-47.L- (LED-), SW-47.SB (SWB), SW-48.L- (LED-), SW-48.SB (SWB), SW-49.L- (LED-), SW-49.SB (SWB), SW-50.L- (LED-), SW-50.SB (SWB), SW-51.L- (LED-), SW-51.SB (SWB), SW-52.L- (LED-), SW-52.SB (SWB), SW-53.L- (LED-), SW-53.SB (SWB), SW-54.L- (LED-), SW-54.SB (SWB), SW-55.L- (LED-), SW-55.SB (SWB), SW-56.L- (LED-), SW-56.SB (SWB), SW-57.L- (LED-), SW-57.SB (SWB), SW-58.L- (LED-), SW-58.SB (SWB), SW-59.L- (LED-), SW-59.SB (SWB), SW-60.L- (LED-), SW-60.SB (SWB), SW-61.L- (LED-), SW-61.SB (SWB), SW-62.L- (LED-), SW-62.SB (SWB), SW-63.L- (LED-), SW-63.SB (SWB), SW-64.L- (LED-), SW-64.SB (SWB), SW-65.L- (LED-), SW-65.SB (SWB), SW-66.L- (LED-), SW-66.SB (SWB), SW-67.L- (LED-), SW-67.SB (SWB), SW-68.L- (LED-), SW-68.SB (SWB), SW-69.L- (LED-), SW-69.SB (SWB), SW-70.L- (LED-), SW-70.SB (SWB), SW-71.L- (LED-), SW-71.SB (SWB), SW-72.L- (LED-), SW-72.SB (SWB), SW-73.L- (LED-), SW-73.SB (SWB), SW-74.L- (LED-), SW-74.SB (SWB), SW-75.L- (LED-), SW-75.SB (SWB), SW-76.L- (LED-), SW-76.SB (SWB), SW-77.L- (LED-), SW-77.SB (SWB), SW-78.L- (LED-), SW-78.SB (SWB), SW-79.L- (LED-), SW-79.SB (SWB), SW-80.L- (LED-), SW-80.SB (SWB); also elsewhere on the board
L41: SW-41.L+ (LED+); also elsewhere on the board
L42: SW-42.L+ (LED+); also elsewhere on the board
L43: SW-43.L+ (LED+); also elsewhere on the board
L44: SW-44.L+ (LED+); also elsewhere on the board
L45: SW-45.L+ (LED+); also elsewhere on the board
L46: SW-46.L+ (LED+); also elsewhere on the board
L47: SW-47.L+ (LED+); also elsewhere on the board
L48: SW-48.L+ (LED+); also elsewhere on the board
L49: SW-49.L+ (LED+); also elsewhere on the board
L50: SW-50.L+ (LED+); also elsewhere on the board
L51: SW-51.L+ (LED+); also elsewhere on the board
L52: SW-52.L+ (LED+); also elsewhere on the board
L53: SW-53.L+ (LED+); also elsewhere on the board
L54: SW-54.L+ (LED+); also elsewhere on the board
L55: SW-55.L+ (LED+); also elsewhere on the board
L56: SW-56.L+ (LED+); also elsewhere on the board
L57: SW-57.L+ (LED+); also elsewhere on the board
L58: SW-58.L+ (LED+); also elsewhere on the board
L59: SW-59.L+ (LED+); also elsewhere on the board
L60: SW-60.L+ (LED+); also elsewhere on the board
L61: SW-61.L+ (LED+); also elsewhere on the board
L62: SW-62.L+ (LED+); also elsewhere on the board
L63: SW-63.L+ (LED+); also elsewhere on the board
L64: SW-64.L+ (LED+); also elsewhere on the board
L65: SW-65.L+ (LED+); also elsewhere on the board
L66: SW-66.L+ (LED+); also elsewhere on the board
L67: SW-67.L+ (LED+); also elsewhere on the board
L68: SW-68.L+ (LED+); also elsewhere on the board
L69: SW-69.L+ (LED+); also elsewhere on the board
L70: SW-70.L+ (LED+); also elsewhere on the board
L71: SW-71.L+ (LED+); also elsewhere on the board
L72: SW-72.L+ (LED+); also elsewhere on the board
L73: SW-73.L+ (LED+); also elsewhere on the board
L74: SW-74.L+ (LED+); also elsewhere on the board
L75: SW-75.L+ (LED+); also elsewhere on the board
L76: SW-76.L+ (LED+); also elsewhere on the board
L77: SW-77.L+ (LED+); also elsewhere on the board
L78: SW-78.L+ (LED+); also elsewhere on the board
L79: SW-79.L+ (LED+); also elsewhere on the board
L80: SW-80.L+ (LED+); also elsewhere on the board
S41: SW-41.SA (SWA); also elsewhere on the board
S42: SW-42.SA (SWA); also elsewhere on the board
S43: SW-43.SA (SWA); also elsewhere on the board
S44: SW-44.SA (SWA); also elsewhere on the board
S45: SW-45.SA (SWA); also elsewhere on the board
S46: SW-46.SA (SWA); also elsewhere on the board
S47: SW-47.SA (SWA); also elsewhere on the board
S48: SW-48.SA (SWA); also elsewhere on the board
S49: SW-49.SA (SWA); also elsewhere on the board
S50: SW-50.SA (SWA); also elsewhere on the board
S51: SW-51.SA (SWA); also elsewhere on the board
S52: SW-52.SA (SWA); also elsewhere on the board
S53: SW-53.SA (SWA); also elsewhere on the board
S54: SW-54.SA (SWA); also elsewhere on the board
S55: SW-55.SA (SWA); also elsewhere on the board
S56: SW-56.SA (SWA); also elsewhere on the board
S57: SW-57.SA (SWA); also elsewhere on the board
S58: SW-58.SA (SWA); also elsewhere on the board
S59: SW-59.SA (SWA); also elsewhere on the board
S60: SW-60.SA (SWA); also elsewhere on the board
S61: SW-61.SA (SWA); also elsewhere on the board
S62: SW-62.SA (SWA); also elsewhere on the board
S63: SW-63.SA (SWA); also elsewhere on the board
S64: SW-64.SA (SWA); also elsewhere on the board
S65: SW-65.SA (SWA); also elsewhere on the board
S66: SW-66.SA (SWA); also elsewhere on the board
S67: SW-67.SA (SWA); also elsewhere on the board
S68: SW-68.SA (SWA); also elsewhere on the board
S69: SW-69.SA (SWA); also elsewhere on the board
S70: SW-70.SA (SWA); also elsewhere on the board
S71: SW-71.SA (SWA); also elsewhere on the board
S72: SW-72.SA (SWA); also elsewhere on the board
S73: SW-73.SA (SWA); also elsewhere on the board
S74: SW-74.SA (SWA); also elsewhere on the board
S75: SW-75.SA (SWA); also elsewhere on the board
S76: SW-76.SA (SWA); also elsewhere on the board
S77: SW-77.SA (SWA); also elsewhere on the board
S78: SW-78.SA (SWA); also elsewhere on the board
S79: SW-79.SA (SWA); also elsewhere on the board
S80: SW-80.SA (SWA); also elsewhere on the board

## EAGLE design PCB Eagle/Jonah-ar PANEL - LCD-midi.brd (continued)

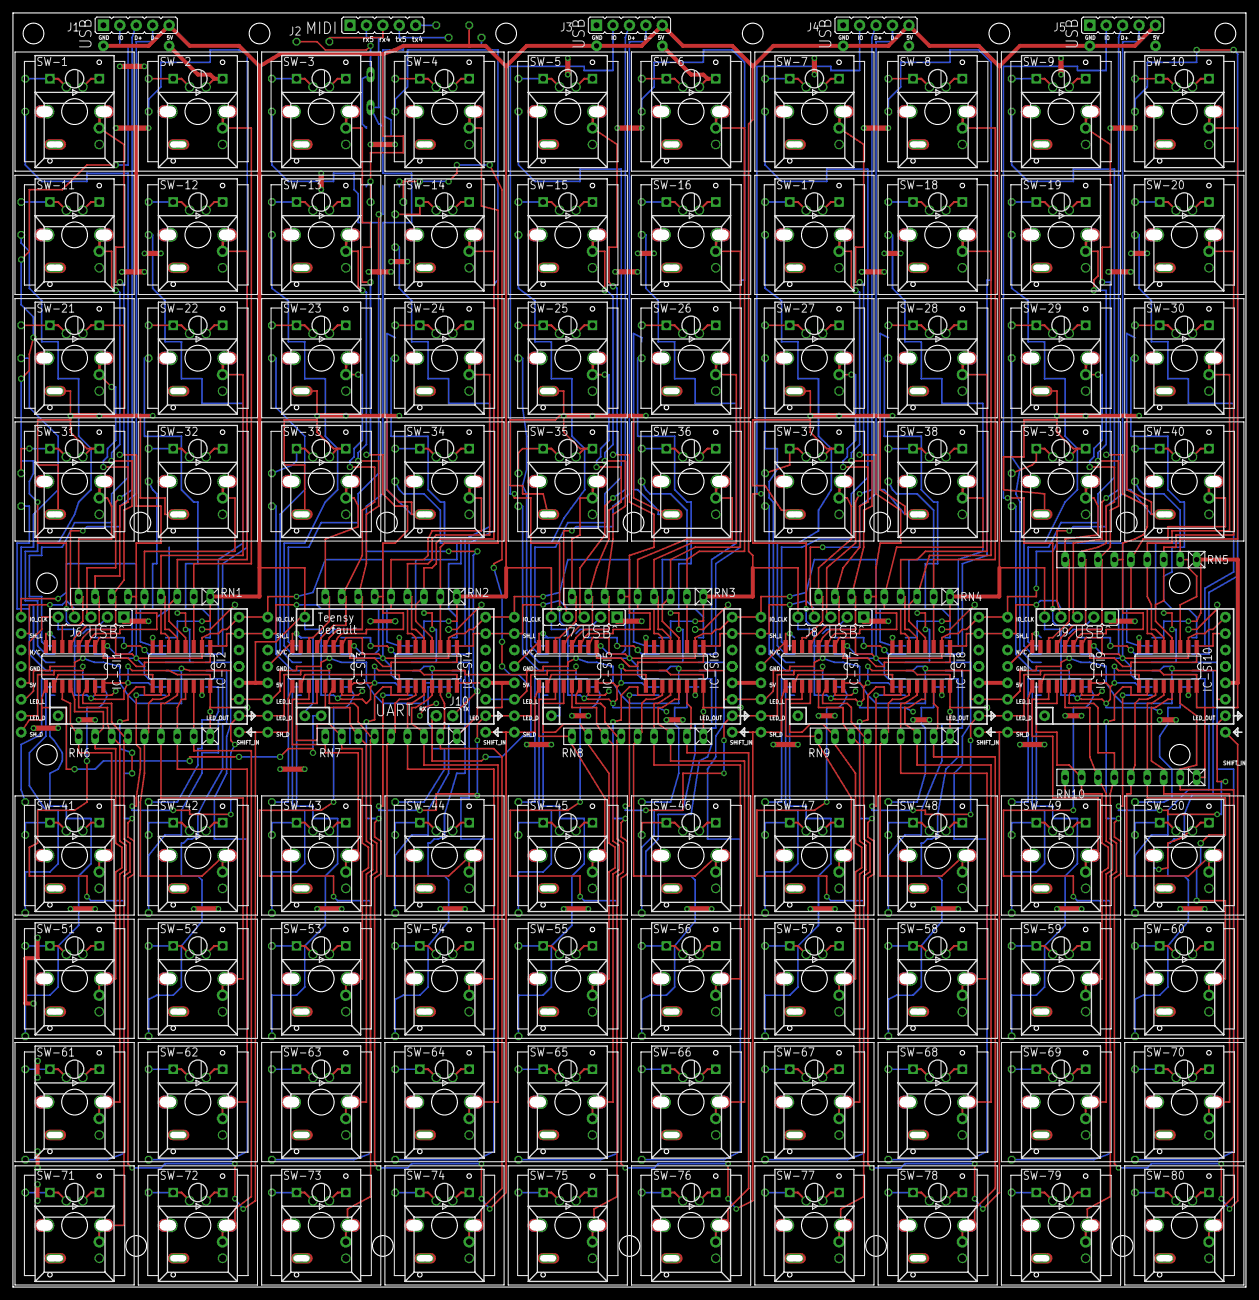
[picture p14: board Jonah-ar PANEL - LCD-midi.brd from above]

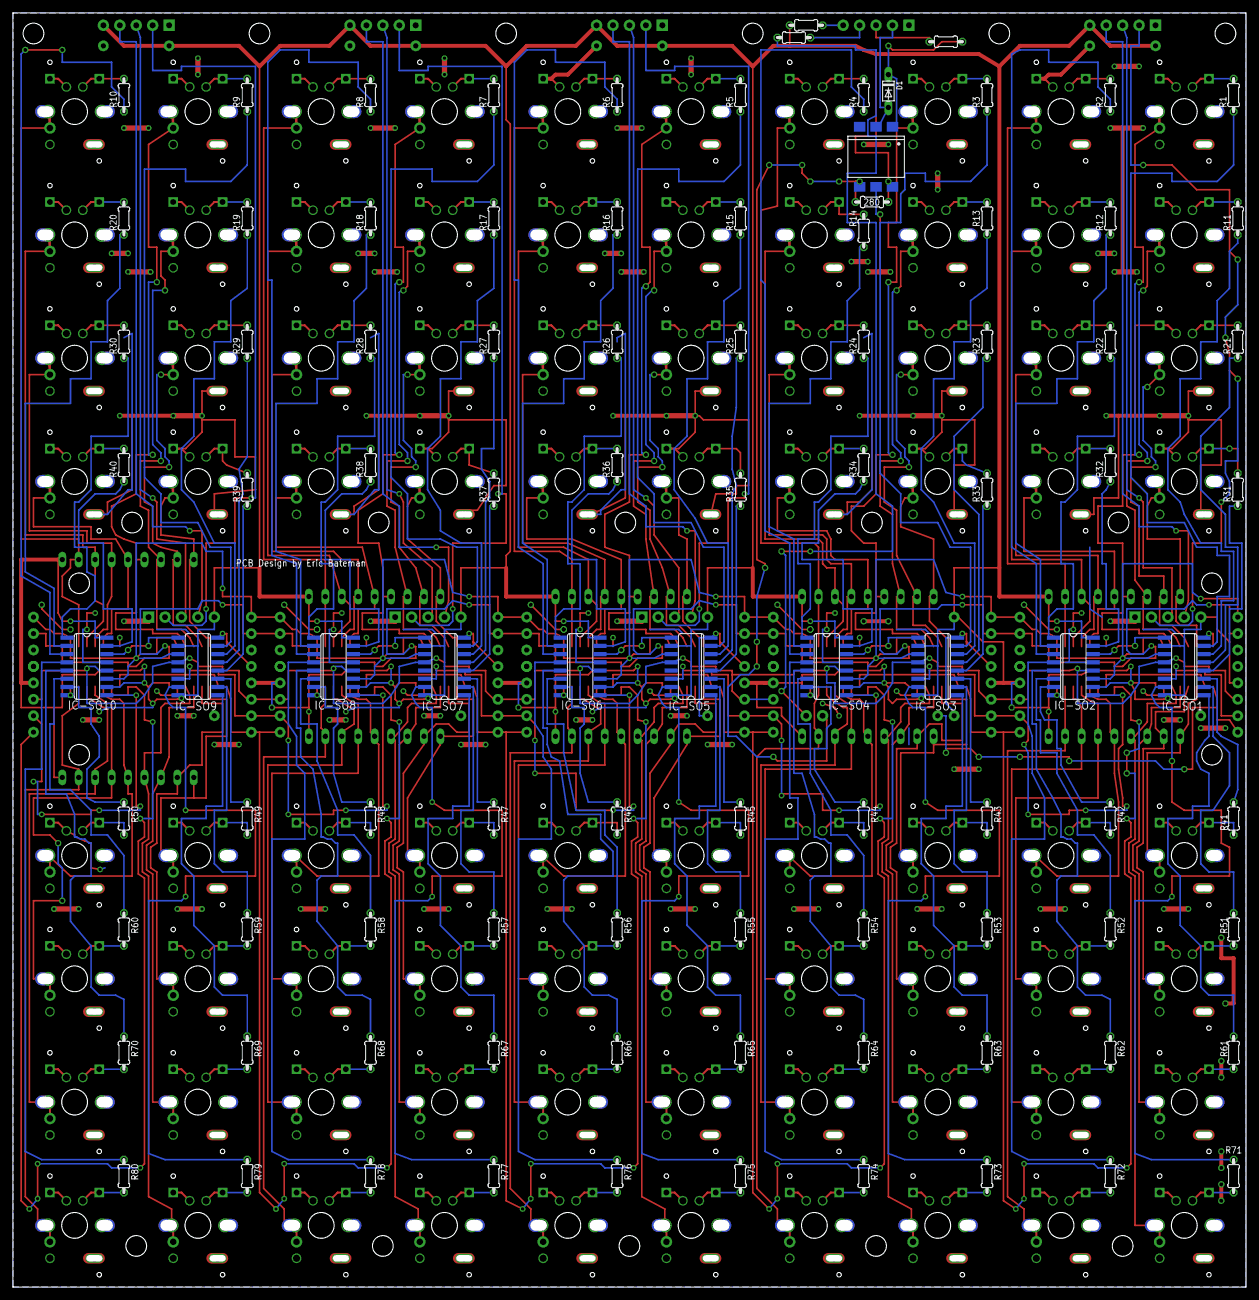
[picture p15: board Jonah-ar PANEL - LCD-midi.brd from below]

Board: 2 copper layers, 190.5 x 196.8 mm, 206 parts (96 on the bottom side), 282 nets.

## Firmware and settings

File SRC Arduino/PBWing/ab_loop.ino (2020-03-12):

void loop() {


      unsigned long CurrentTime = millis();
      while (millis() - CurrentTime < 1000){
        doShift();
        MIDI.read();
        usbMIDI.read();
      }
/*
      Serial.print("sw0: ");
      Serial.print(sw[0]);
      Serial.print(" sw1: ");
      Serial.print(sw[1]);
      Serial.print(" sw2: ");
      Serial.print(sw[2]);
      Serial.print(" sw3: ");
      Serial.print(sw[3]);
      Serial.print(" sw4: ");
      Serial.println(sw[4]);

    
// debug, count up LEDs

    for (int i = 0; i < MAXBUTTONS; i++) {
      led[i] = 1;
     
      unsigned long CurrentTime = millis();
      while (millis() - CurrentTime < 500){
        doShift();
      }
    }
    memset(led,0,sizeof(led));
*/
    
}

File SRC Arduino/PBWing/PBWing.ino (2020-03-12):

// pruning down code from MIDIALF for actual JONAH hardware/PCB

//********** Define Pins and I/O
#define   LCD_DATA4	  19
#define   LCD_DATA5	  18
#define   LCD_DATA6	  17
#define   LCD_DATA7	  16
#define   LCD_RS	    21
#define   LCD_EN	    20

#define   IO_CLOCK	  11

#define   SW_DATA	    0
#define   SW_LATCH	  22

#define   LED_DATA	  1  // PCB rev 1 this has to be hand wired, oops!
#define   LED_LATCH	  23

#define   MAXBUTTONS  80
#define   OFFSET      24       // offet for MIDI notes

//**********

#define PULSE_WIDTH_USEC   5
#define SW_SLOWDOWN 10  // slowdown in MS
#define FLASHSPEED  100

int led[MAXBUTTONS];       // 80 LEDs
int sw[MAXBUTTONS];        // 80 switches

int swState[MAXBUTTONS];       // 80 switches
int swPrevState[MAXBUTTONS];     // Previous switch state

int noteTran[] = {

  70, 71, 72, 73, 74, 75, 76, 77, 78, 79,       
  60, 61, 62, 63, 64, 65, 66, 67, 68, 69,       
  50, 51, 52, 53, 54, 55, 56, 57, 58, 59,       
  40, 41, 42, 43, 44, 45, 46, 47, 48, 49,       

  30, 31, 32, 33, 34, 35, 36, 37, 38, 39,       
  20, 21, 22, 23, 24, 25, 26, 27, 28, 29,       
  10, 11, 12, 13, 14, 15, 16, 17, 18, 19,       
  0, 1, 2, 3, 4, 5, 6, 7, 8, 9        
};

unsigned long swTimer[MAXBUTTONS];

int swTran[] = {
  30, 20, 10, 0,       70, 60, 50, 40, 
  31, 21, 11, 1,       71, 61, 51, 41, 
  32, 22, 12, 2,       72, 62, 52, 42, 
  33, 23, 13, 3,       73, 63, 53, 43, 
  34, 24, 14, 4,       74, 64, 54, 44,   
  35, 25, 15, 5,       75, 65, 55, 45,   
  36, 26, 16, 6,       76, 66, 56, 46,   
  37, 27, 17, 7,       77, 67, 57, 47,   
  38, 28, 18, 8,       78, 68, 58, 48,   
  39, 29, 19, 9,       79, 69, 59, 49           
};

int ledTran[] = {                 // Translate the shift-out to the relative LED positions  
  49, 59, 69, 79, 9, 19, 29, 39, 
  8, 18, 28, 38, 48, 58, 68, 78, 
  47, 57, 67, 77, 7, 17, 27, 37, 
  6, 16, 26, 36, 46, 56, 66, 76, 
  45, 55, 65, 75, 5, 15, 25, 35, 
  4, 14, 24, 34, 44, 54, 64, 74, 
  43, 53, 63, 73, 3, 13, 23, 33, 
  2, 12, 22, 32, 42, 52, 62, 72, 
  41, 51, 61, 71, 1, 11, 21, 31, 
  0, 10, 20, 30, 40, 50, 60, 70 
};
